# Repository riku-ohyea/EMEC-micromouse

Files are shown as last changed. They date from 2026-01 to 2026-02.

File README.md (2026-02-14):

# EMEC Micromouse – UQMARS 2026

This repository contains the code, hardware files, and documentation for the EM Engineering Club (EMEC) Micromouse robot developed for the 2026 UQMARS Micromouse Competition.

The repository was actively used during development and competition for testing, iteration, and file management. This README provides an overview of the robot design, hardware modifications, and software architecture.

🎥 Test Day Video
(May update with official competition footage)
https://www.youtube.com/watch?v=nQMq9lbTZGA

# Hardware

Our design is heavily based on the UQMARS starter Micromouse platform:

🔗 https://github.com/uqmars/starter-micromouse

The original repository contains:
- PCB design files
- Chassis CAD files
- Starter parts list

**Modifications We Made**

We modified the following subsystems:
- Wall detection sensors
- Battery configuration

**Wall Detection Sensors
**
We replaced the original wall detection system with three PiicoDev VL53L1X Time-of-Flight (ToF) distance sensors:

🔗 https://core-electronics.com.au/piicodev-laser-distance-sensor-vl53l1x.html

Three sensors were used (front, left, right).

To mount them, we designed and 3D-printed custom holders:

🔗 05 custom hardware/tof_holder_v01.stl

To connect the sensors to the starter kit PCB, the following components were used:
- PiicoDev Breadboard Adapter, https://core-electronics.com.au/piicodev-breadboard-adapter.html
- Adafruit PCA9546 4-Channel I2C Multiplexer (TCA9546A compatible), https://core-electronics.com.au/adafruit-pca9546-4-channel-stemma-qt-qwiic-i2c-multiplexer-tca9546a-compatible.html

**I2C Configuration
**
GPIO 4 and GPIO 5 were used for I2C communication. Refer to the source code for exact pin mapping and sensor indexing.

**Battery
**
The lighter, lower-capacity LiPo battery was replaced with the higher-capacity battery included in the starter kit to improve runtime and reliability during competition runs.

# Software
The software was rewritten from the original starter kit code.

**Goals of the Rewrite
**
- Enable compatibility with the Micromouse simulator
- Allow algorithm testing without hardware
- Enable parallel development within the team
- Maintain a shared logic structure between simulation and hardware

Micromouse simulator used:
🔗 https://github.com/mackorone/mms

The implementation was completed under competition time constraints, so the structure is functional but not optimised for readability.

Main hardware testing branch:
🔗 02 test hardware code/09 MM DRIVERS/0208_bot1test02

**Maze Strategy
**
Our robot performed:
- Exploration phase only
- No optimized speed run using a known maze
Unlike the winning team, our robot did not perform a second optimized run after mapping the maze.
Between runs, we tuned motion parameters using a “bonk” maneuver to refine wall alignment and increase maze-solving speed.

**Code Architecture
**
Below is an overview of the main files:
- main.py - Entry point of the system.Handles integration of all classes and execution flow.
- PIDMotor.py - Motor control module. Motor initialization, Encoder reading, PID control loops, Distance and angle movement functions
- API.py - Hardware abstraction layer (apologies for the poor file name). Responsible for real-world robot interaction. In theory, replacing this file with the Micromouse simulator API should allow the same logic to run in simulation (not fully tested).
- Maze.py - Defines the Maze object. Stores discovered walls and maze structure during exploration.
- Mouse.py - Tracks current position, orientation, movement decisions
- Direction.py - Utility class for handling directional logic and conversions.
- TOFSensors.py - Handles ToF sensor configuration, I2C multiplexer interaction, sensor helper functions.
- Other Files - Additional drivers for sensors and hardware components.

# Acknowledgements
Much of the foundational work is based on:
- Micromouse Simulator by Mackorone, https://github.com/mackorone
- PiicoDev drivers by Core Electronics, https://github.com/CoreElectronics
Our contribution primarily involved integrating these systems and adapting them to work cohesively for our hardware and competition requirements.

# Final Notes
We hope this repository is helpful for anyone attempting the Micromouse challenge, competing in UQMARS, or building their own autonomous maze-solving robot.

---
# EMEC-micromouse
EscapeManorEngineeringClub. Micrmouse team
Micrmouse team documents, code, and files

Report: https://github.com/riku-ohyea/EMEC-micromouse/blob/main/06%20Submission%20Documents/EMEC%20Micromouse%20Documentation%202026.pdf

Video: https://youtu.be/1biOx0Q3veI

Team Google Drive: https://drive.google.com/drive/folders/1eSfBlvatloG3tSRXEPzZx30s3_RQ47VF?usp=drive_link (Only accessible to team members)

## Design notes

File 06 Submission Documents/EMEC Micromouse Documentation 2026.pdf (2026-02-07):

# EM Engineering Club UQ MARS Micromouse 2026 Report

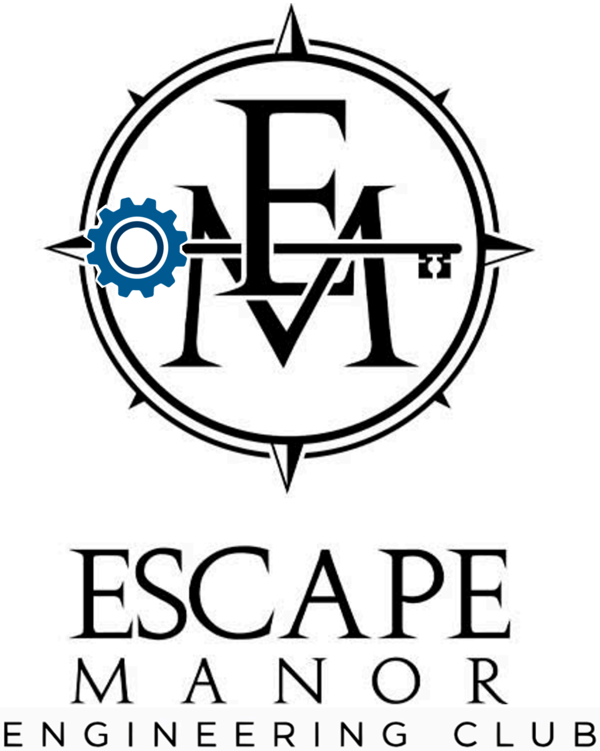
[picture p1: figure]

Members: Jack Crans, Kristopher Dickinson, Kale Dickinson, Lily Boyle, Riku Oya Date: 7 February 2026

## Acknowledgements

We thank the UQ MARS team for organising the Micromouse competition and for allowing non-students to participate. Opportunities to compete in robotics challenges after university are limited in Australia, and we greatly appreciate being included.

We also thank the team for providing a high-quality Micromouse kit, which significantly improved the learning experience and reduced setup time.

## Overview

This report documents the design of two robots developed by the EM Engineering Club for the UQ MARS Micromouse 2026, held on 8 February 2026.

This document covers the design and implementation details of each robot.

## Video

https://youtu.be/1biOx0Q3veI

## Robot 1 Design – UQ MARS Kit-Based Robot

Source Code

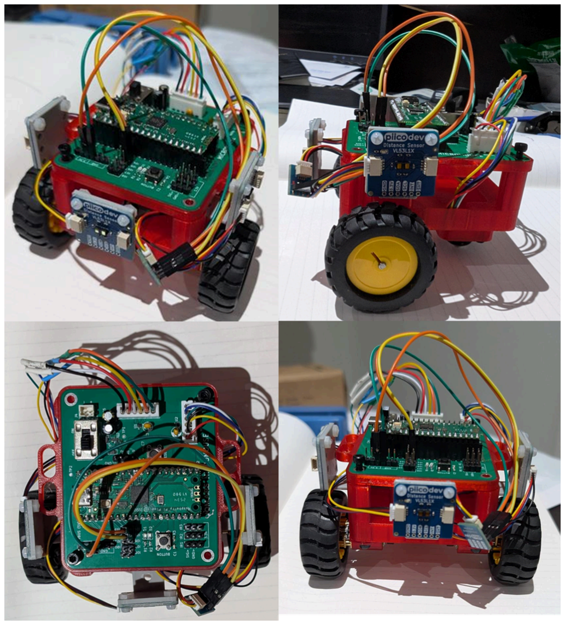
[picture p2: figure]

The most up-to-date source code is available at: https://github.com/riku-ohyea/EMEC-micromouse/tree/main/02%20test%20hardware%20code/09%20MM%20DRIVERS/0207_bonk_test3 (https://github.com/riku-ohyea/EMEC-micromouse/tree/main/02%20test%20hardware%20code/09%20MM%20DRIVERS/0207_bonk_test3)

Minor tuning or adjustments may be made on the competition day. The latest commit on the team GitHub repository should be considered the final version used.

Design

Hardware

- Based on the standard UQ MARS Micromouse kit
- IR obstacle sensors were replaced with three I2C Time-of-Flight (ToF) distance sensors

- An I2C multiplexer is used to allow all three ToF sensors to operate on the same bus

Software

- Uses a basic flood-fill algorithm to assign cost values to maze cells
- The robot selects the lowest-cost path based on currently known walls
- ToF sensors are positioned to detect:
- Left wall
- Right wall
- Front wall
- Sensors are limited to detecting walls in the current cell only
- A PIO-based encoder reader is used to reliably read encoder values at higher motor speeds

Control

- Encoder-based PID motor control (no integral term)
- Encoder-based PID used for:
- Forward movement to the next grid cell
- Heading correction and turning
- ToF-based PID used for heading correction when side walls are confidently detected
- A backing manoeuvre is used when a rear wall is detected, allowing the robot to correct heading using its flat rear surface

## CAD

- Main chassis:
https://github.com/uqmars/starter-micromouse/tree/master/CAD
- ToF sensor holders (×3): https://github.com/riku-ohyea/EMEC-micromouse/blob/main/05%20custom%20hardware/tof_holder_v01.stl (https://github.com/riku-ohyea/EMEC-micromouse/blob/main/05%20custom%20hardware/tof_holder_v01.stl)

## Circuit Schematics

- Main schematic:
https://github.com/uqmars/starter-micromouse/blob/master/PCB%20Design/Schematic.p df (https://github.com/uqmars/starter-micromouse/blob/master/PCB%20Design/Schematic.pdf)
- The I2C multiplexer with three connected ToF sensors is wired to:
- 3.3V
- GND
- GPIO 4
- GPIO 5
- Original obstacle sensors were removed from the circuit

## Prices of Components

Name | Type | Material | Qt y | Cos t | Subto tal | Link
Top Plate 3D Print | 3D Printed | PLA | 1 | -
Base Plate 3D Print | 3D Printed | PLA | 1 | -
Motor Clamp 3D Print | 3D Printed | PLA | 2 | -
Caster Ball Extension 3D Print | 3D Printed | PLA | 1 | -
PiicoDev Laser Distance Sensor VL53L1X | Purchased | | 3 | $18. 85 | $56.5 5 | Core Electronics (https://core-electronics.com.au/piicodev-laser-distance-sensor-vl53l1x.html)
N20 Motor with Encoder (6V 100RPM) | Purchased | | 2 | $9.3 3 | $18.6 6 | Aliexpress (https://www.aliexpress.com/item/1005007571722097.html)
N20 Motor 43mm Wheel | Purchased | | 2 | $1.6 0 | $3.20 | Aliexpress (https://www.aliexpress.com/item/1005007811650639.html)
Caster Ball | Purchased | | 1 | $0.5 0 | $0.50 | Aliexpress (https://www.aliexpress.com/item/1005008096943126.html)
M3 x 8mm Hex Button Screw | Purchased | Stainless Steel | 15 | $0.1 0 | $1.50 | Aliexpress (https://www.aliexpress.com/item/32967225441.html?curPageLogUid=vMDo78oz88UZ)
Polymer Lithium Ion Battery (LiPo) 3.7V 1100mAh | Purchased | | 1 | $8.9 5 | $8.95 | Core Electronics (https://core-electronics.com.au/polymer-lithium-ion-battery-1000mah-38458.html)
USB-C Lipo Charger | Purchased | | 1 | $7.6 0 | $7.60 | Core Electronics (https://core-electronics.com.au/makerverse-usb-c-lipo-charger.html)
Raspberry Pi Pico | Purchased | | 1 | $3.8 9 | $3.89 | Aliexpress (https://www.aliexpress.com/item/1005007393927221.html)
JST XH 6-Pin Male/Female Pair (straight) | Purchased | | 2 | $0.3 3 | $0.66 | Aliexpress (https://www.aliexpress.com/item/1005007080333485.html)
JST PH 2-Pin Male PCB Connector (straight) | Purchased | | 1 | $0.0 2 | $0.02 | Aliexpress (https://www.aliexpress.com/item/1005004708000514.html)
PiicoDev Adapter for Breadboards | Purchased | | 1 | $1.6 5 | $1.65 | Core Electronics (https://core-electronics.com.au/piicodev-breadboard-adapter.html)
Adafruit PCA9546 4-Channel I2C Multiplexer | Purchased | | 1 | $7.7 5 | $7.75 | Core Electronics (https://core-electronics.com.au/adafruit-pca9546-4-channel-stemma-qt-qwiic-i2c-multiplexer-tca9546a-compatible.html)
Micromouse PCB Assembly | Internally Manufactured | | 1 | -
16 X 7.8 X 10.5 MM, 6 MM RAISED | Purchased | | 1 | $0.9 8 | $0.98

20V 2.4A 140M@4.5V,2.4A 900MW 1. | Purchased | 2 | $0.1 0 | $0.20
40V 550MV@2A 2A SOD-123FL | Purchased | 1 | $0.1 1 | $0.11
12-V, 1.76-A BRUSHED DC MOTOR DR | Purchased | 2 | $0.7 0 | $1.40
RES 10K OHM 5% 1/16W 0402 | Purchased | 2 | $0.0 0 | $0.00
RES 100K OHM 1% 1/16W 0402 | Purchased | 1 | $0.0 0 | $0.00
RES 220 OHM 5% 1/16W 0402 | Purchased | 2 | $0.0 0 | $0.00
CAP CER 0.1UF 50V X7R 0603 | Purchased | 3 | $0.0 2 | $0.06
LED GREEN CLEAR SMD | Purchased | 1 | $0.1 6 | $0.16
LED RED CLEAR SMD | Purchased | 1 | $0.2 1 | $0.21
| | | Total | $114. 05

## Robot 2 Design – UQ MARS Kit-Based Robot

Still currently in development.

## Appendix

Random Maze Generator

https://github.com/riku-ohyea/EMEC-micromouse/tree/main/Maze%20generator

A random maze generator was developed to assist with algorithm testing. Current limitations:

- Requires further updates to integrate with the maze simulator used
- Can occasionally generate mazes with inaccessible regions

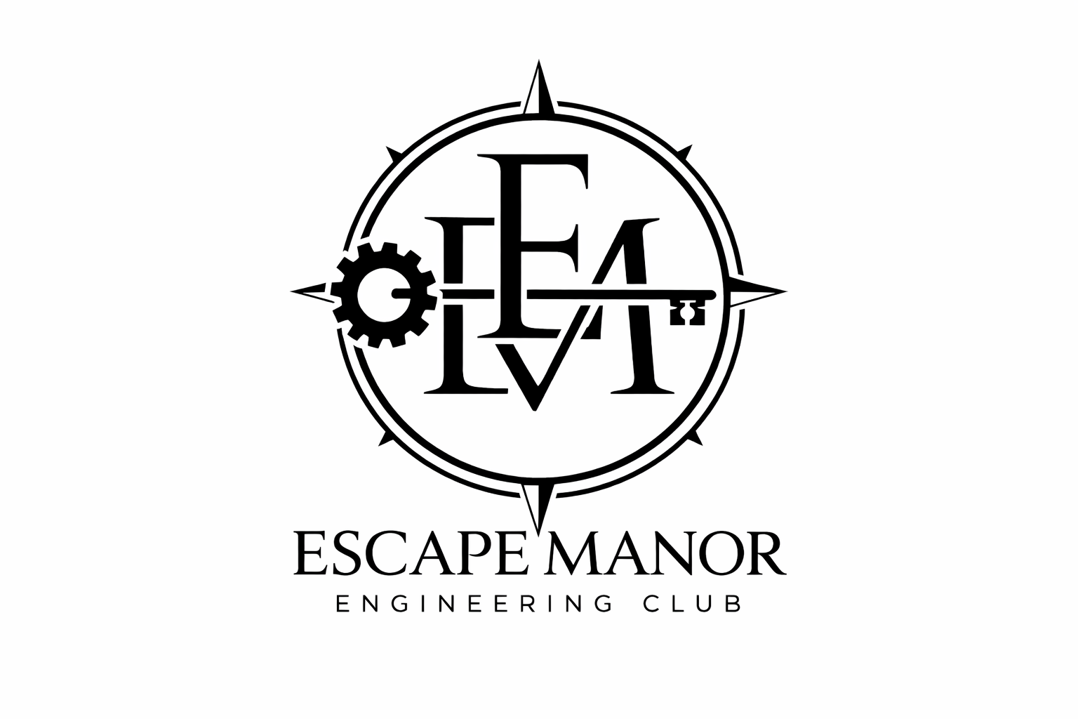
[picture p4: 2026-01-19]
01 team docs/00 logos/ChatGPT Image Jan 18, 2026, 08_36_46 AM.png

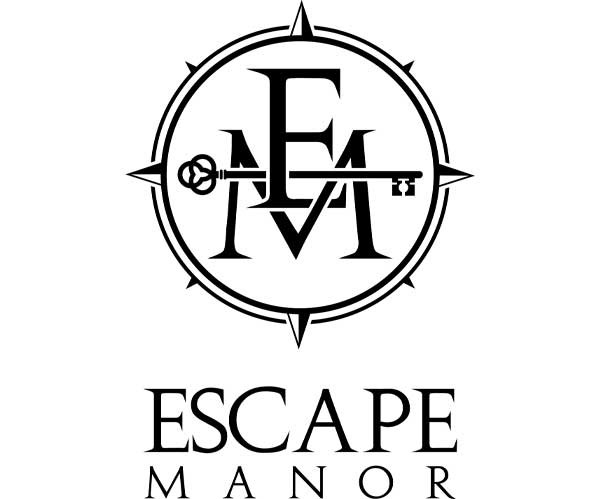
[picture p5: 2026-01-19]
01 team docs/00 logos/Picture1.jpg

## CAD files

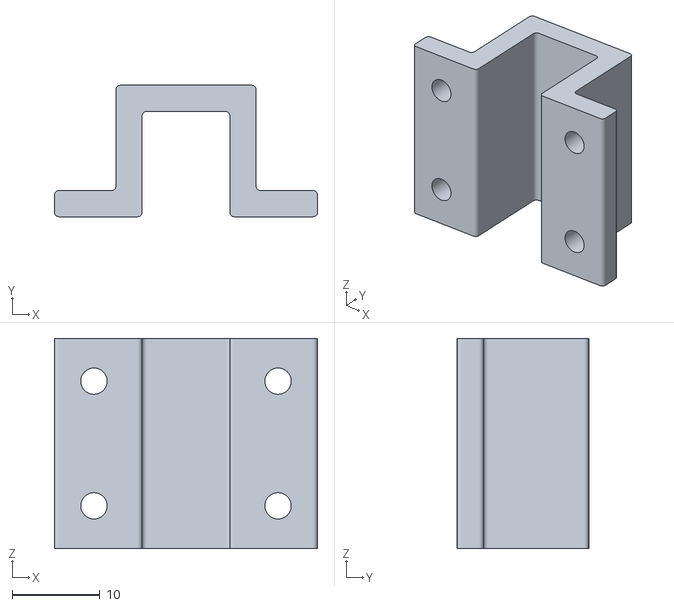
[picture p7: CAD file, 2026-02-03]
05 custom hardware/Part Studio 1 - Motor Clips.stl
30.0 x 15.0 x 24.0

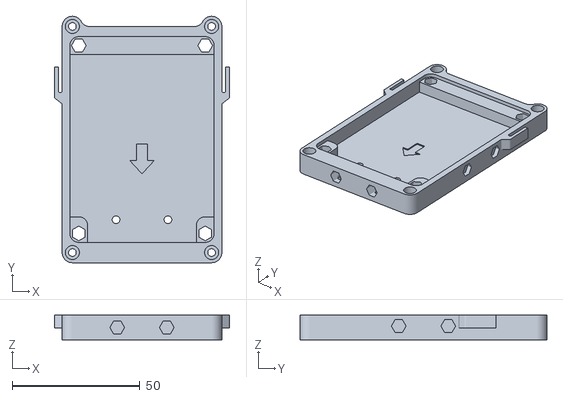
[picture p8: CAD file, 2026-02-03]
05 custom hardware/Part Studio 1 - Top Slab.stl
68.5 x 96.5 x 9.60

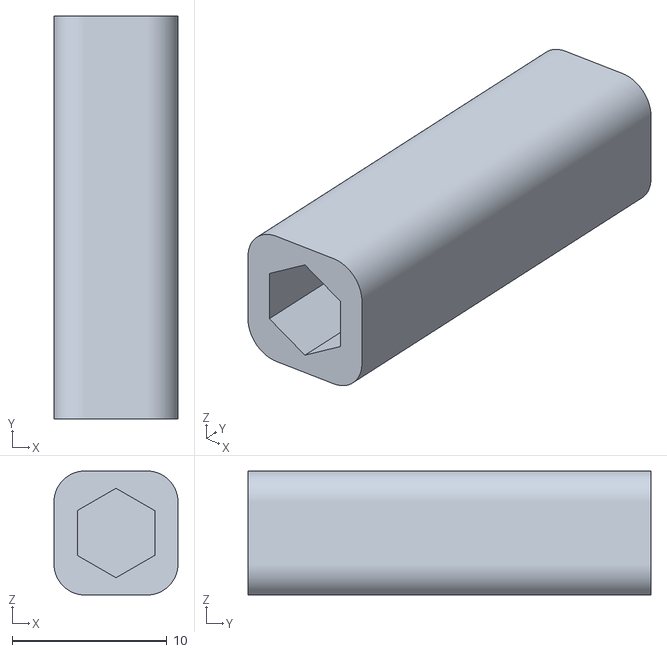
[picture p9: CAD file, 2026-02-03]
05 custom hardware/Part Studio 1 - Standard Pylon.stl
8.00 x 26.0 x 8.00

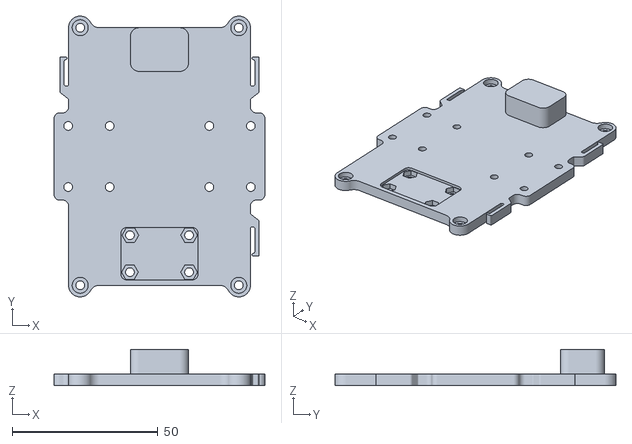
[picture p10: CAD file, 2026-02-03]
05 custom hardware/Part Studio 1 - Bottom Slab.stl
72.5 x 96.5 x 12.5

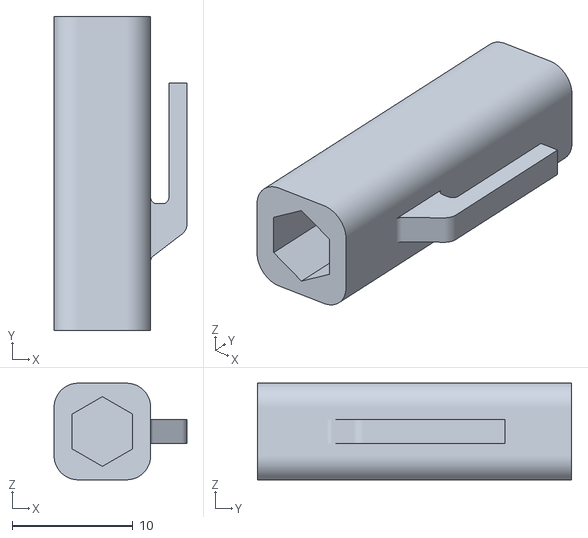
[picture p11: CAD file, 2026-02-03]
05 custom hardware/Part Studio 1 - Clip Pylon.stl
11.0 x 26.0 x 8.00

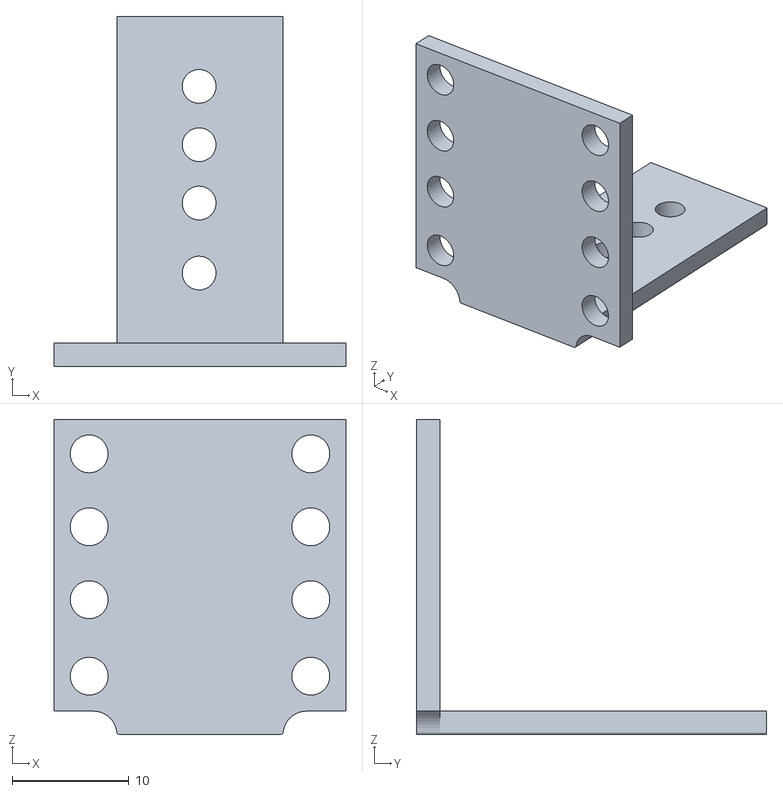
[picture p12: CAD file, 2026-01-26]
05 custom hardware/tof_holder_v01.stl
25.0 x 30.0 x 27.0

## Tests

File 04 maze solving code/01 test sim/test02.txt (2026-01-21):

+-+-+-+-+-+
|         |
+ + +-+ +-+
| |   | | |
+ + +-+ + +
| |   |   |
+ + +-+ + +
| | |   | |
+ + +-+ + +
| |       |
.-+-+-+-+-+

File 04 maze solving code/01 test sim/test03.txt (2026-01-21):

+-+-+-+
|     |
+ +-+ +
| | | |
+ + + +
| |   |
.-+-+-+

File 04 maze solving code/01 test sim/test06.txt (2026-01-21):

o---o---o---o---o---o---o---o---o---o---o---o---o---o---o---o---o
|                                                               |
o   o   o   o   o   o   o   o   o   o   o   o   o   o   o   o   o
|                                                               |
o   o   o   o   o   o   o   o   o   o   o   o   o   o   o   o   o
|                                                               |
o   o   o   o   o   o   o   o   o   o   o   o   o   o   o   o   o
|                                                               |
o   o   o   o   o   o   o   o   o   o   o   o   o   o   o   o   o
|                                                               |
o   o   o   o   o   o   o   o   o   o   o   o   o   o   o   o   o
|                                                               |
o   o   o   o   o   o   o   o   o   o   o   o   o   o   o   o   o
|                                                               |
o   o   o   o   o   o   o   o   o   o   o   o   o   o   o   o   o
|                                                               |
o   o   o   o   o   o   o   o   o   o   o   o   o   o   o   o   o
|                                                               |
o   o   o   o   o   o   o   o   o   o   o   o   o   o   o   o   o
|                                                               |
o   o   o   o   o   o   o   o   o   o   o   o   o   o   o   o   o
|                                                               |
o---o---o---o---o---o   o   o   o   o   o   o   o   o   o   o   o
|       |       |   |                                           |
o   o   o   o   o   o   o   o   o   o   o   o   o   o   o   o   o
|   |       |   |   |                                           |
o   o   o   o   o   o   o   o   o   o   o   o   o   o   o   o   o
|   |   | G     |   |                                           |
o---o   o   o---o   o   o   o   o   o   o   o   o   o   o   o   o
|       |       |   |                                           |
o   o   o---o   o   o   o   o   o   o   o   o   o   o   o   o   o
| S |       |       |                                           |
o---o---o---o---o---o---o---o---o---o---o---o---o---o---o---o---o

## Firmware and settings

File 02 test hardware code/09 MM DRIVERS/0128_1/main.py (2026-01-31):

from rp2 import PIO, StateMachine, asm_pio
from machine import Pin, PWM, Timer
import micropython
import utime
import math


class QuadratureDecoder:
    """
    Track rotary encoder position using programmable IO controller (PIO)
    """

    def __init__(self, pin_a, pin_b):
        self.sm = StateMachine(1, self._encoder, freq=125_000_000, in_base=pin_b, jmp_pin=pin_a)

        # Reset counter
        self.sm.put(0)
        self.sm.exec("pull()")
        self.sm.exec("out(x, 32)")

        # Start PIO
        self.sm.active(1)

    @micropython.viper
    def read(self) -> int:
        """
        Get the current position of the encoder
        """
        self.sm.exec("in_(x, 32)")
        x = self.sm.get()

        # Convert unsigned to signed
        # There doesn't seem to be a native way to get this from PIO
        if x & 0x80000000:
            x -= 0xFFFFFFFF
            
        return int(x)
        
    @asm_pio(autopush=True, push_thresh=32)
    def _encoder():
        """
        SPDX-FileCopyrightText: 2022 Jamon Terrell <github@jamonterrell.com>
        SPDX-License-Identifier: MIT
        https://github.com/jamon/pi-pico-pio-quadrature-encoder/
        """
        label("start")
        wait(0, pin, 0)         # Wait for CLK to go low
        jmp(pin, "WAIT_HIGH")   # if Data is low
        mov(x, invert(x))           # Increment X
        jmp(x_dec, "nop1")
        label("nop1")
        mov(x, invert(x))
        label("WAIT_HIGH")      # else
        jmp(x_dec, "nop2")          # Decrement X
        label("nop2")
        
        wait(1, pin, 0)         # Wait for CLK to go high
        jmp(pin, "WAIT_LOW")    # if Data is low
        jmp(x_dec, "nop3")          # Decrement X
        label("nop3")
        
        label("WAIT_LOW")       # else
        mov(x, invert(x))           # Increment X
        jmp(x_dec, "nop4")
        label("nop4")
        mov(x, invert(x))
        wrap()


class Motor():
    def __init__(self):
        # self.encoder = QuadratureDecoder(Pin(2), Pin(3))
        self.encoder = QuadratureDecoder(Pin(19), Pin(22))

        # self.pwm = PWM(Pin(13), freq=20000, duty_u16=0)
        # self.fwd = Pin(15, mode=Pin.OUT, value=0)
        # self.rev = Pin(14, mode=Pin.OUT, value=0)
        self.pwm_m1 = PWM(Pin(21), freq = 2000)
        self.pwm_m2 = PWM(Pin(20), freq = 2000)
        
        self.max_out = 65535
    
        self.read = self.encoder.read
        
    def brake(self):
        # self.pwm.duty_u16(0)
        # self.rev.off()
        # self.fwd.off()
        self.pwm_m1.duty_u16(0)
        self.pwm_m2.duty_u16(0)
        
    # def freewheel(self):
    #     self.pwm.duty_u16(0)
    #     self.rev.on()
    #     self.fwd.on()
                
    def set_speed(self, percent: float):
        clamped = max(min(100, percent), -100) / 100.0
        output = int(clamped * self.max_out)

        if output > -100 and output < 100:
            # Stop if the value is small enough to not do anything
            self.brake()
        elif output > 0:
            # self.rev.off()
            # self.fwd.on()
            self.pwm_m1.duty_u16(abs(output))
            self.pwm_m2.duty_u16(0)
        else:
            # self.fwd.off()
            # self.rev.on()
            self.pwm_m2.duty_u16(abs(output))
            self.pwm_m1.duty_u16(0)

        # self.pwm.duty_u16(abs(output))


class PidMotor(Motor):
    def __init__(self, Kp, Ki, Kd):
        super().__init__()

        # PID settings
        self.Kp = Kp
        self.Ki = Ki
        self.Kd = Kd

        # PID state
        self.integral = 0
        self.last_error = 0
        self.last_update = utime.ticks_us()

        # Inputs
        self.target = 0
        self._smoothed_target = 0
        self.enable = False
        
        self._timer = Timer(period=1, mode=Timer.PERIODIC, callback=self._update)
        
    @micropython.native
    def _update(self, t):
        pos = self.encoder.read()

        now = utime.ticks_us()
        dt = (now - self.last_update)/1e6
        
        self._smoothed_target += (self.target - self._smoothed_target) * 0.02

        if self.enable:
            error = self._smoothed_target - pos
            self.integral = self.integral + dt * error
            derivative = (error - self.last_error)/dt
            output = self.Kp * error + self.Ki * self.integral + self.Kd * derivative
        else:
            error = 0
            self.integral = 0
            output = 0
            
        if not self.enable:
            self.brake()
        else:
            self.set_speed(output)

        self.last_update = now
        self.last_error = error    


def cleanup_pios():
    """ Free any allocated PIOs from a previous interactive run """
    for i in range(6):
        try:
            rp2.PIO(i).remove_program()
        except:
            continue


# Motor sensing and control
cleanup_pios()
motor = PidMotor(
    Kp=0.8, # Proportional
    Ki=1.8, # Integral
    Kd=0.0, # Derivative
)

motor.max_out = 65535

# PID Demo
count = 0
motor.target = 120
# motor.enable = True
# 
# start = utime.ticks_us()
# 
# while True:
#     now = utime.ticks_us() - start
#     motor.target = motor.target * -1
#     utime.sleep(1)
#
motor.enable = False
while True:
    print(motor.encoder.read())
    utime.sleep_ms(100)

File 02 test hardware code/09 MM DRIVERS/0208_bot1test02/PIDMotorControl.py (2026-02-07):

# MicroPython (RP2040 / Pico)
# - PIO-based quadrature-ish counter from your working example
# - Differential-drive PID for distance + heading (encoder difference)
#
# Update motor PWM pins to match your hardware!

from rp2 import StateMachine, asm_pio
from machine import Pin, PWM
import utime
import math
import struct

# ----------------------------
# PIO encoder (from your file)
# ----------------------------
@asm_pio(autopush=True, push_thresh=32)
def encoder():
    label("start")
    wait(0, pin, 0)         # Wait for CLK to go low
    jmp(pin, "WAIT_HIGH")   # if Data is low
    mov(x, invert(x))       # Increment X (using invert trick)
    jmp(x_dec, "nop1")
    label("nop1")
    mov(x, invert(x))
    label("WAIT_HIGH")      # else
    jmp(x_dec, "nop2")      # Decrement X
    label("nop2")

    wait(1, pin, 0)         # Wait for CLK to go high
    jmp(pin, "WAIT_LOW")    # if Data is low
    jmp(x_dec, "nop3")      # Decrement X
    label("nop3")

    label("WAIT_LOW")       # else
    mov(x, invert(x))       # Increment X
    jmp(x_dec, "nop4")
    label("nop4")
    mov(x, invert(x))
    wrap()

def u32_to_i32(v):
    # StateMachine.get() returns unsigned; convert to signed 32-bit
    return struct.unpack("!i", struct.pack("!I", v & 0xFFFFFFFF))[0]

class PIOEncoder:
    def __init__(self, sm_id, clk_pin, data_pin):
        # Your example:
        # in_base = Pin(data_pin)
        # jmp_pin = Pin(clk_pin)
        self.sm = StateMachine(
            sm_id,
            encoder,
            freq=125_000_000,
            in_base=Pin(data_pin, Pin.IN, Pin.PULL_UP),
            jmp_pin=Pin(clk_pin, Pin.IN, Pin.PULL_UP),
        )
        self.sm.active(1)
        self._last = self.read()

    def read(self):
        # Grab current X register value (as in your example)
        self.sm.exec("in_(x, 32)")
        return u32_to_i32(self.sm.get())

    def delta(self):
        cur = self.read()
        d = cur - self._last
        self._last = cur
        return d

# ----------------------------
# Motor driver (2 PWM pins)
# ----------------------------
class Motor:
    def __init__(self, in1_pin, in2_pin, pwm_freq=2000, invert=False):
        # self.in1 = PWM(Pin(in1_pin), freq=pwm_freq)
        # self.in2 = PWM(Pin(in2_pin), freq=pwm_freq)
        self.in1 = PWM(Pin(in1_pin))
        self.in2 = PWM(Pin(in2_pin))
        self.in1.freq(pwm_freq)
        self.in2.freq(pwm_freq)
        self.invert = invert
        self.set(0)

    def set(self, power):
        """
        power: -1.0 .. +1.0
        """
        if self.invert:
            power = -power

        power = max(-1.0, min(1.0, power))

        if power >= 0:
            duty = int(power * 65535)
            self.in1.duty_u16(duty)
            self.in2.duty_u16(0)
        else:
            duty = int((-power) * 65535)
            self.in1.duty_u16(0)
            self.in2.duty_u16(duty)

    def stop(self):
        self.in1.duty_u16(0)
        self.in2.duty_u16(0)

# ----------------------------
# PID controller
# ----------------------------
class PID:
    def __init__(self, kp, ki, kd, out_min=-1.0, out_max=1.0, i_limit=1.0):
        self.kp = kp
        self.ki = ki
        self.kd = kd
        self.out_min = out_min
        self.out_max = out_max
        self.i_limit = abs(i_limit)
        self.i = 0.0
        self.prev_err = 0.0
        self.prev_t = utime.ticks_ms()

    def reset(self):
        self.i = 0.0
        self.prev_err = 0.0
        self.prev_t = utime.ticks_ms()

    def update(self, err, dt):
        # Integrator with clamp (anti-windup)
        self.i += err * dt
        if self.i > self.i_limit:
            self.i = self.i_limit
        elif self.i < -self.i_limit:
            self.i = -self.i_limit

        d = (err - self.prev_err) / dt if dt > 0 else 0.0
        self.prev_err = err

        out = self.kp * err + self.ki * self.i + self.kd * d
        if out > self.out_max:
            out = self.out_max
        elif out < self.out_min:
            out = self.out_min
        return out

# ----------------------------
# Differential drive controller
# ----------------------------
class DiffDrive:
    def __init__(self, left_motor, right_motor, left_enc, right_enc,
                 wheel_diam_cm=4.4, wheelbase_cm=9.9,
                 ticks_per_wheel_rev=1075):

        self.L = left_motor
        self.R = right_motor
        self.eL = left_enc
        self.eR = right_enc

        self.wheel_diam_cm = wheel_diam_cm
        self.wheelbase_cm = wheelbase_cm
        self.ticks_per_wheel_rev = ticks_per_wheel_rev

        self.wheel_circ_cm = math.pi * wheel_diam_cm
        self.ticks_per_cm = ticks_per_wheel_rev / self.wheel_circ_cm

        # PID gains (STARTING POINTS — you will tune)
        # Distance PID drives average encoder to target.
        self.pid_dist = PID(kp=0.00475, ki=0.0000, kd=0.000075, out_min=-1, out_max=1, i_limit=0.5)
        # Heading PID drives difference encoder to 0 (straight) or to target (turn).
        self.pid_head = PID(kp=0.00250, ki=0.0000, kd=0.000030, out_min=-1, out_max=1, i_limit=0.5)

        # PIDMotorControl.py inside DiffDrive.__init__
        self.pid_wall = PID(
             kp=0.00510, ki=0.0, kd=0.000,   # start conservative, tune later
             out_min=-1, out_max=1,
             i_limit=0.5
             )

        # how often we try to refresh TOF (ms). Your motor loop is 3ms. TOF cannot keep up.
        self.tof_period_ms = 20


        # Motion loop params
        self.dt = 0.005  #  Hz
        self.min_power = 0.4  # helps overcome stiction; tune for your robot
        self.done_band_ticks = 20  # stop when within this many ticks
        self.max_time_s = 10.0  # safety timeout per command; adjust as needed

    def _apply_deadband(self, u):
        if u == 0:
            return 0
        if 0 < u < self.min_power:
            return self.min_power
        if -self.min_power < u < 0:
            return -self.min_power
        return u

    def reset_pids(self):
        self.pid_dist.reset()
        self.pid_head.reset()
        self.pid_wall.reset()

    def stop(self):
        self.L.stop()
        self.R.stop()

    def cm_to_ticks(self, cm):
        return int(cm * self.ticks_per_cm)
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

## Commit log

2026-01-11 test code with pi pico
2026-01-18 Create temp
    adding a temporary file to create a new circuit design directory before adding the kicad files
2026-01-18 Committing circuit design files
    [Micromouse_current_all_parts.kicad_pcb, Micromouse_current_all_parts.kicad_sch]
2026-01-18 Minor Changes
    Committing most up to date versions of files
    [Micromouse_current_all_parts.kicad_pcb]
2026-01-19 file organisation
    [Micromouse_current_all_parts.kicad_pcb, Micromouse_current_all_parts.kicad_sch]
2026-01-19 file org
    [Micromouse_current_all_parts.kicad_pcb, Micromouse_current_all_parts.kicad_sch]
2026-01-20 3 sensors on MARS kit
    using multiplexer with gpio5,4.
2026-01-20 Final Schematic Update
    Contains the pcb design files sent for fabrication
    [Micromouse_current_all_parts.kicad_pcb, Micromouse_current_all_parts.kicad_sch]
2026-01-24 pid tests
2026-01-25 pid tests 1
2026-01-25 Changes to driver files
    changes to spin motor. Absolute values used instead. Was sending negative values
2026-01-25 encoder sweep added
    for PID, encodere testing. Identifying operating range for PWM that still records good enough encoder values. -75 to 70 with USB power
2026-01-25 Create Maze_generator_cleaned
    Current version as of 25/01/26 without unnecessary previous steps
2026-01-25 Left-Hand Movement
    Left-handed movement for testing tile numbering. Robot currently does not stop when hitting center tile. Flood-fill rework to come
    [API.py]
2026-01-27 PID testing
2026-01-28 Updated solver
    Updated the solver module to incorporate a robot controller that, for the moment, simulates the input and outputs of the robot and its sensors
2026-01-31 backup code
    for maze solver and pid stuff
2026-01-31 PID component & Floodfill
    Each component working to minimum standards. Next all integration including wall sensing component.
2026-02-02 Backing up full integration
    starting on tof heading correction
    [API.py, Direction.py, Maze.py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]
2026-02-03 Modelling done
    Micromouse STL files
    [Part Studio 1 - Bottom Slab.stl, Part Studio 1 - Clip Pylon.stl, Part Studio 1 - Motor Clips.stl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]
2026-02-04 TOF live tuning
    Some tuning and further testing on the maze defnitely required. Next step would be to have the gyro...?
2026-02-04 Updated solver
    Updated the flood fill to include logic for gates (limited) added extra branch in case anyone is working on old versions of this program and don't want their work overwritten
2026-02-07 updated solver
    New updated solver with sensors and multi-attempt pathfinding logic
